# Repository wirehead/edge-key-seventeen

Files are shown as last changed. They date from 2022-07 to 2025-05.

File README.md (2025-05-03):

# edge-key-seventeen: A 17 key standard-layout numeric keypad plus encoders

I like numeric keypads.  They come in handy when I am working with CAD packages and stuff.  So you can see this as a piece of quiet rebellion against the world of hipster 40% or 60% fancy keyboards but one that still gives you a durable, fancy, interesting, artisanal, hand-crafted, mechanically-keyed product at the end of it.

## Prior art

This is partially developed using [Ruiqi Mao's Keyboard PCB guide](https://github.com/ruiqimao/keyboard-pcb-guide) as a reference... except that I'd suggest you don't actually use that guide as a reference because it's got some inaccuracies and at this point is old and unmaintained.  It turns out that, because I was designing it around parts that I already was comfortable with using and based it off of prior designs, I'd managed to sidestep all of the problems.  The current hotness is arguably the [ai03 Keyboard PCB](https://wiki.ai03.com/books/pcb-design) guide which seems to be newer and more accurate.

Otherwise, this has design lineage through a few earlier designs I cooked up but won't bother posting because they were mostly design experiments and aren't really useful for anyone.

## The design

### Design goals

* Be mostly standard in being designed for the QMK firmware, use Cherry MX keyswitches and standard-sized keycaps, etc.
* Contain the 17 keys of a numeric keypad, plus maybe some encoders for the funs.
* Look vaguely interesting as just a PCB.
* Use parts I already had in my parts bin for other projects.

### Concrete technical spec

* 17 keys in the standard layout so you can use pretty much any standard-layout numeric keypad caps.
* 2 rotary encoders with push-buttons.
* ATMega32u4 processor
* USB-C port
* Extra ESD protection diodes and a polyfuse for durability
* Programming port that you shouldn't actually need to ever use.
* 9 4-pin SK6812 "NeoPixel" RGB LEDs pointed downward for underglow
* 6 M2.5 mounting holes
* Not quite able to fit in the 10cm x 10cm box because of the size of the keys.
* Puns on the silkscreen

### USB protection

I did a bunch of digging and datasheet reading.

Given that I'm plugging this into the USB port on my computer, I tend to go for safety.  Thus, there's a ESD diode to protect the USB lines from spikes, there's a polyfuse on the power line so it won't use too much power, there's the required capacitors, and there's a decoupling network to keep the EMI from the cable sheath from crossing over to the ground plane.  This is more than most of the development boards.

I also added a polyfuse in case you short power to ground so it will reduce the chances that things go really bad.

### Routing scheme

Col: PF0, PD4, PD5, PD3, PD2
Row: PB6, PC7, PC6. PB5, PB4
Encoders: PF5/PF6, PF1/PF4
Col -> Row

Neopixel: PB7

Numlock LED: PF7

## BOM

|Reference	 |Quantity	 |Value	 |Footprint|
|---|---|---|---|
|C10 	| 1	| 4.7 nF	| 0805 |
|C1,C2 	| 2	| 22 pF	| 0805 |
|C3 	| 1	| 10 uF	| 0805 |
|C4 	| 1	| 1 uF	| 0805 |
|C5,C6,C7,C8 	| 4	| 0.1 uF	| 0805 | 
|D1,D2,D3,D4,D5,D6,D7,D9,D10,D11,D12,D13,D14,D15,D16,D17,D18,D27,D28 | 19	1N4148	| SOD123 / Axial |
|D19,D20,D21,D22,D23,D24,D25,D26,D29 	| 9	| SK6812	| 5050 PLCC4 |
|D30 | 1 | 5mm LED | |
|D8 	| 1	| PRTR5V0U2X_215	| TO-253-4 |
|F1 	| 1	| 500 mA Polyfuse	| 1206 |
|H1-H6 	| 6	| Mounting Hole	| M2.5 |
|J1 	| 1	| MicroUSB	| GCT USB4085-GF-A |
|J2 	| 1	| AVR-ISP-6	| 2x03 2.54mm pitch vertical SMD |
|MX1,MX2,MX3,MX4,MX5,MX6,MX7,MX9,MX10,MX11,MX12,MX13,MX14,MX17 | 14	| Cherry MX	|1U |
|MX8 MX15 	| 2	| Cherry MX	| 2U Vertical |
|MX16 	| 1	| Cherry MX	| 2U Horizontal |
|R1 	| 1	| 1M | 0603 |
|R2,R3 	| 2	| 22 | 0603 |
|R4,R5	| 2	| 10k | 0805 |
|R6,R8  | 2 | 5.1k | 0603 | 
|R7 | 1	| 1 M | 0603 |
|R9,R10 | 1	| 330 | 0805 |
|S1 | 1	| Toggle switch	| C&K KSR223GLFG | 
|SW1,SW2 | 2	| Rotary_Encoder_Switch	| PEC11R-4215F-S0024-0-0-0 |
|U1 | 1	| ATMEGA32U4 | TQFP-44 |
|Y1 | 1	| 16 MHz | HC49-U |

## Construction

The gerber files are as I upload to JLCPCB to be fabbed.

If other people start wanting to try and fab this board, I'll write an actual proper assembly guide. :)

Either way, the important points to consider are:

* Everything should be solderable with a regular old temperature-controlled ESD-protected soldering iron.
* You don't need to populate J2 unless you get yourself in deep trouble.
* The keyboard diodes are hybrid footprints that can use either a SOD-123 surface mount diode or an axial one.  I actually find SOD-123's easier to solder all told but I'm probably at least a bit odd.
* You can use either PCB-mount or plate-mount keyswitches and there are holes for PCB-mounted stabilizers.
* You can use a set of Mill-Max 7305-0-15-15-47-27-10-0 maybe the new 3305-1-15-15-47-27-10-0 receptacle connectors so that the keyswitches can be hot-swapped -- The 3305-X series is a new part specifically designed for keyswitches.

### Initial bootstrapping

You should just be able to program a freshly constructed board to the USB port and use the QMK programming tool to put an appropriate firmware on the board with the default bootloader.

I need to actually submit the upstream patches for QMK.

### Mounting holes

There are 6 M2.5 sized mounting holes in semi-convenient locations.

### Chassis design

This will appear later, still working on it!

## Changelog

### v1.0 rev 1

### v1.0 rev 2

* MicroUSB replaced with USB-C
* RS-187R05A2-DS button replaced with KSR223G LFG
* RG-49 Crystal a 3.2x2.5mm SMT 
* KiCAD 6.x instead of KiCAD 5.x

### Things I would change next time

* I might try to trim a few mm off of each of the edges.
* I might remove the hybrid SOD123/Axial feature because I actually solder SOD123's faster than I solder axial parts these days.
* The programming port is kinda annoying in the layout and I guess I need to look at more alternatives in the rare case you need to bootloader it.

## License



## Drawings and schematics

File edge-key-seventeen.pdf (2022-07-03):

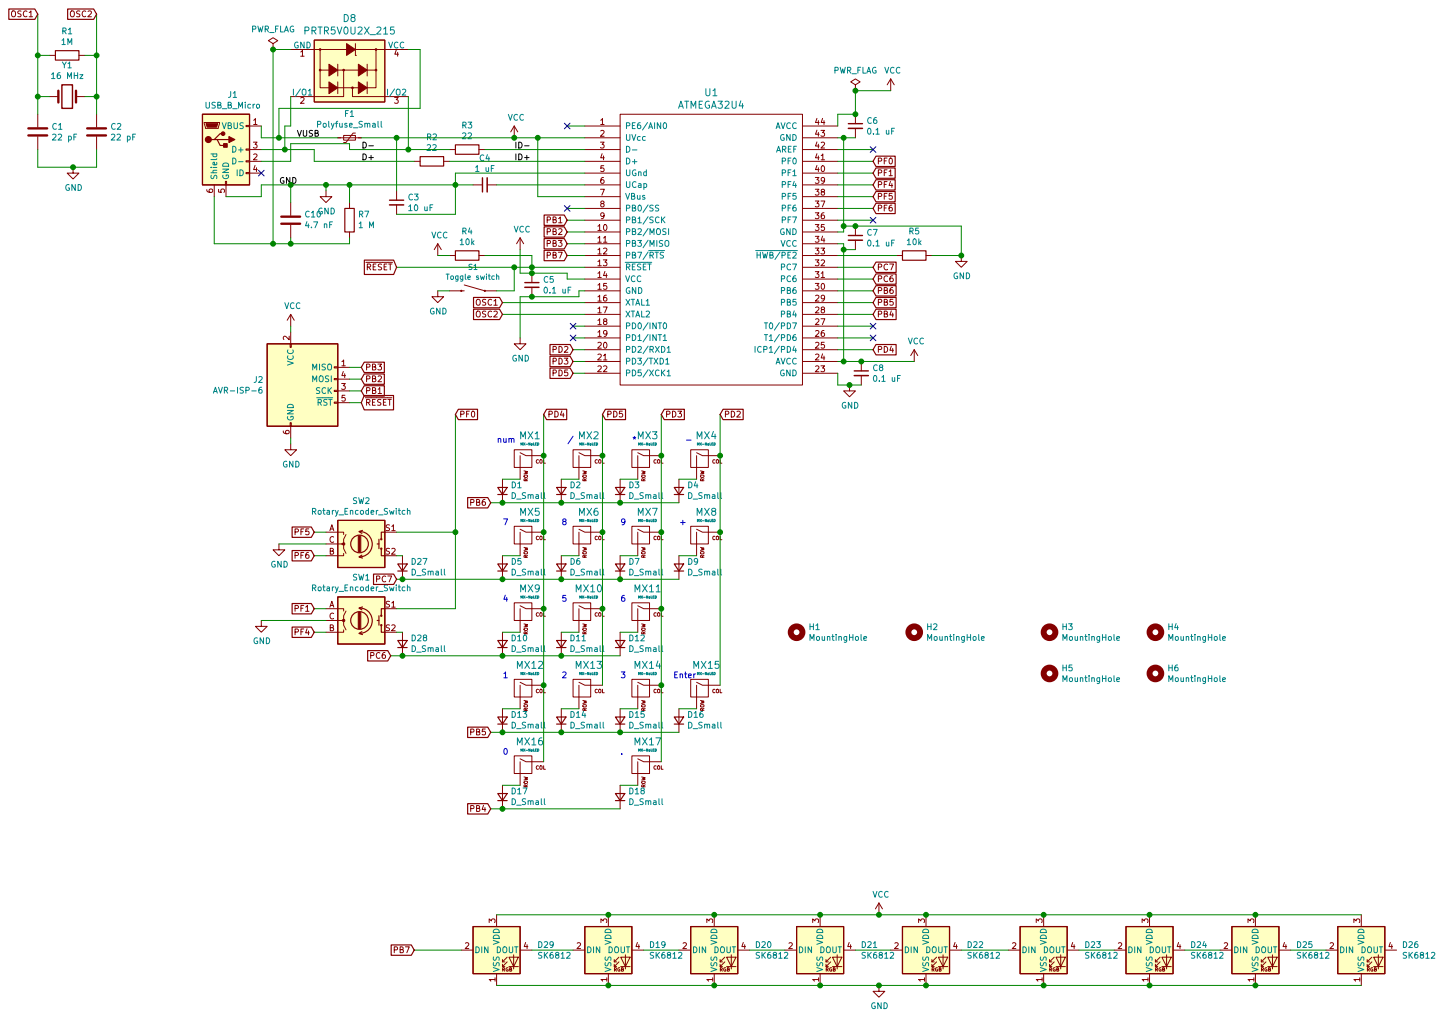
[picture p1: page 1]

2 SCK 3 MOSI 4 RST 5 GND

MX-NoLED COL ROW MX3

MX-NoLED COL ROW MX12

MX-NoLED COL ROW MX16

3 DOUT 4 D19 SK6812 VSS RGB 1 DIN 2 VDD

3 DOUT 4 D24 SK6812 VSS RGB 1 DIN 2 VDD

3 DOUT 4 D25 SK6812 VSS RGB 1 DIN 2 VDD

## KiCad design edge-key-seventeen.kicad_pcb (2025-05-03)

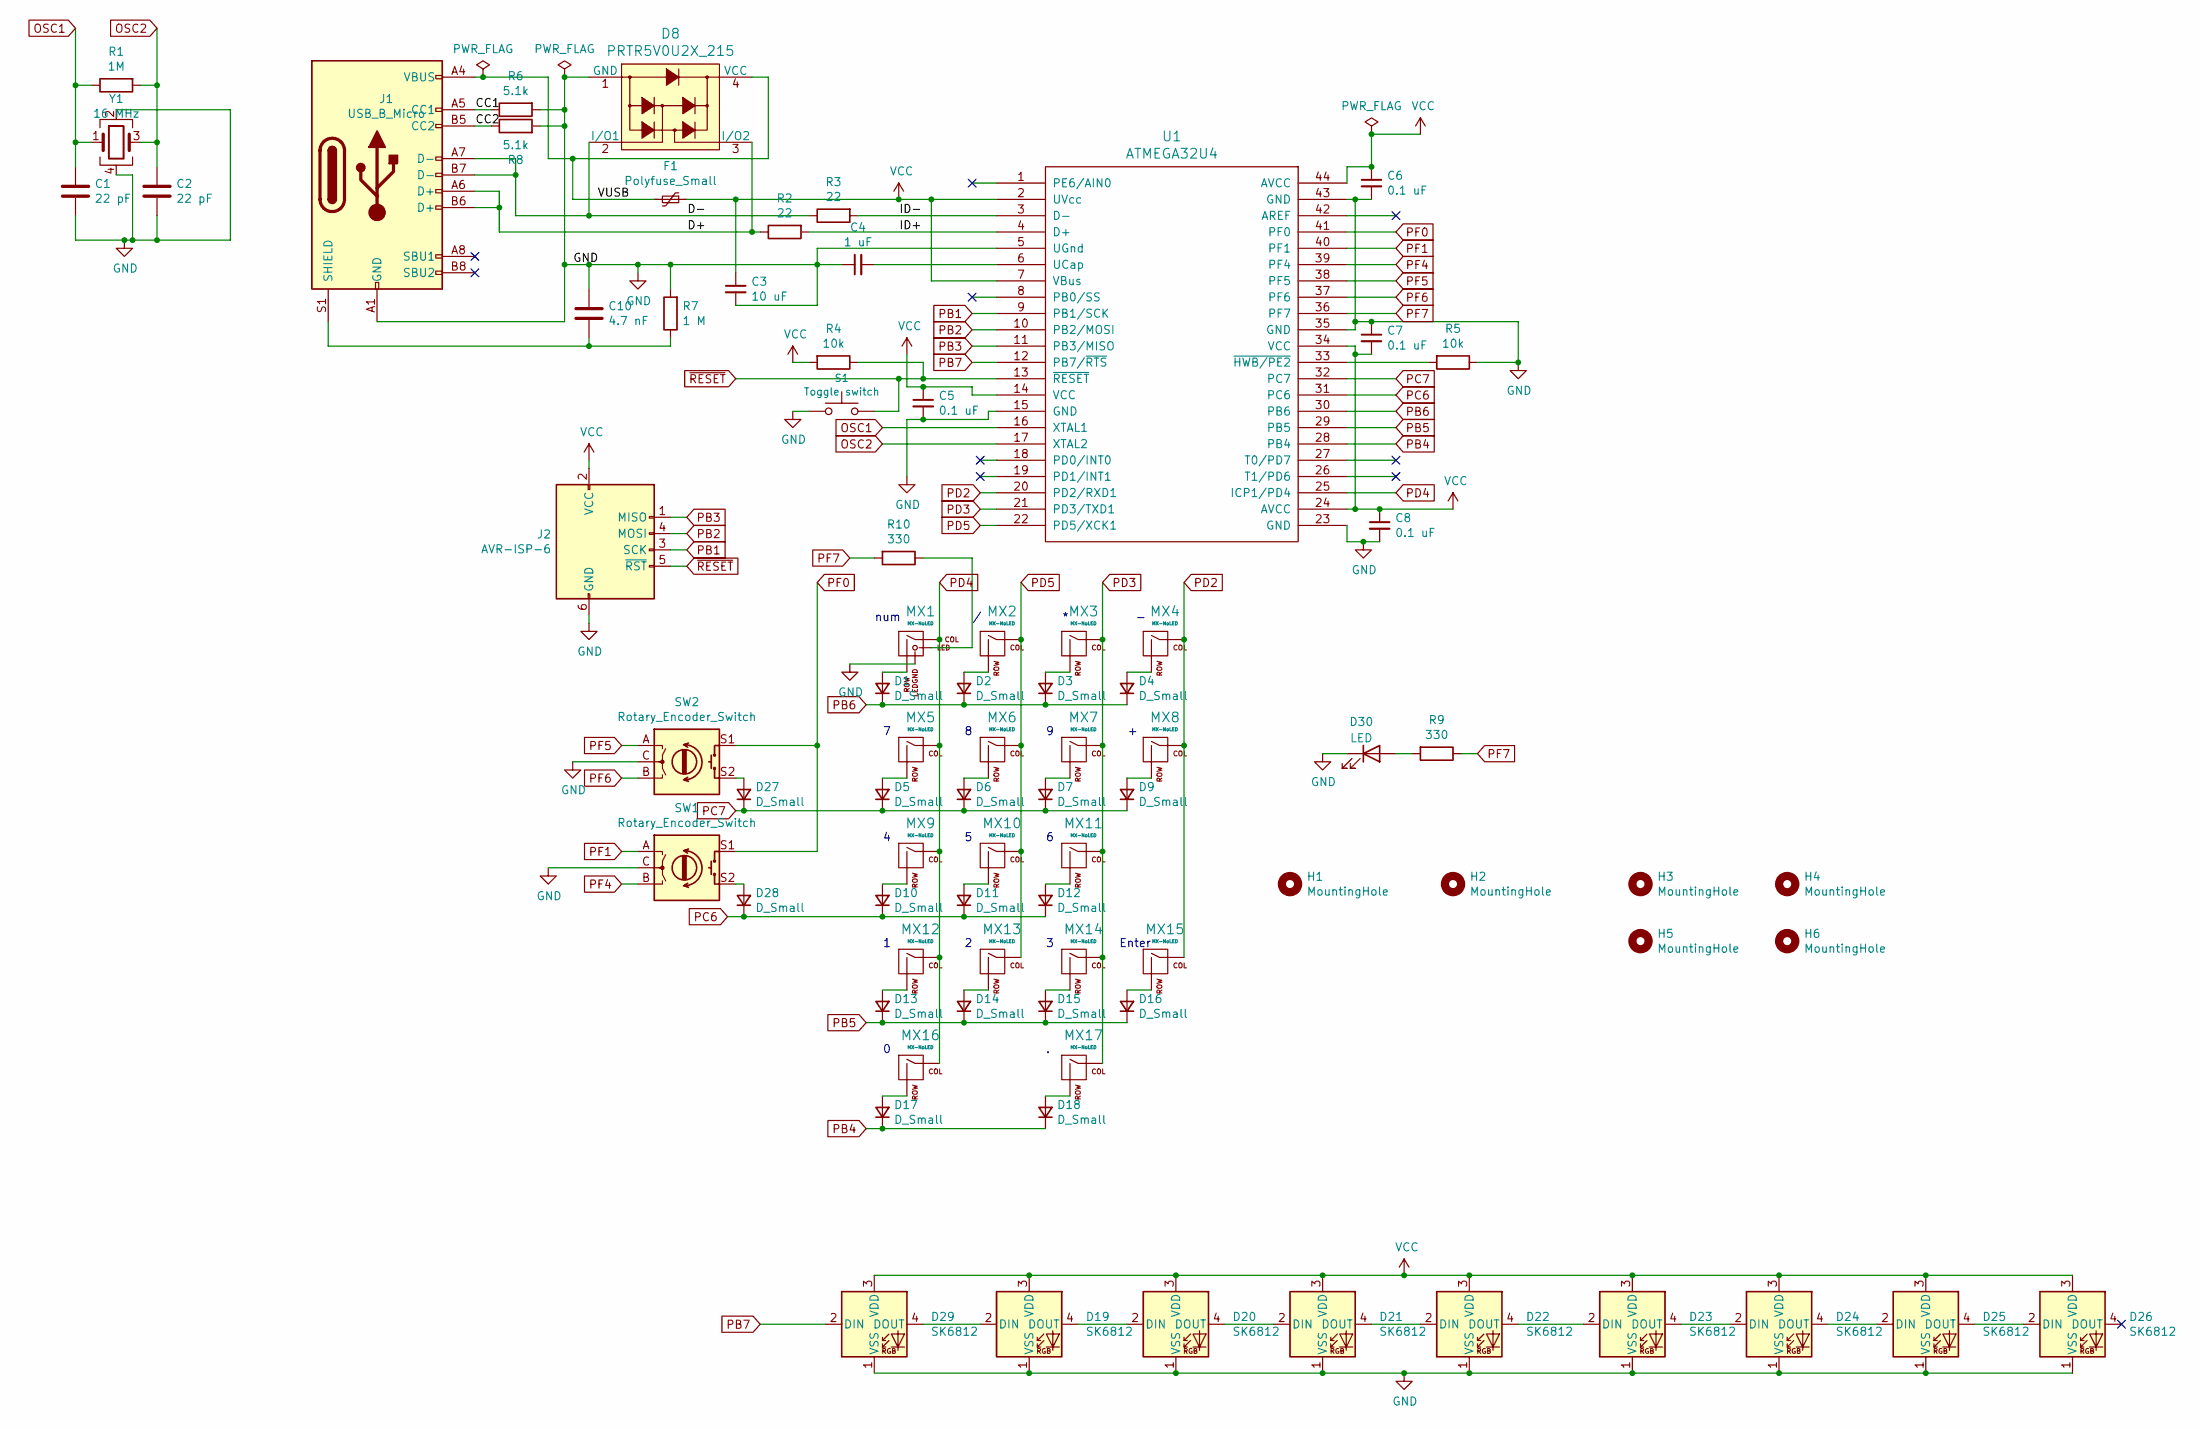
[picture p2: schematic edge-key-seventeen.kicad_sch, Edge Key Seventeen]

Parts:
C1, C2: 22 pF; C_0805_2012Metric_Pad1.15x1.40mm_HandSolder
C3: 10 uF; C_0805_2012Metric_Pad1.15x1.40mm_HandSolder
C4: 1 uF; C_0805_2012Metric_Pad1.15x1.40mm_HandSolder
C5, C6, C7, C8: 0.1 uF; C_0603_1608Metric_Pad1.08x0.95mm_HandSolder
C10: 4.7 nF; C_0603_1608Metric_Pad1.08x0.95mm_HandSolder
D1, D2, D3, D4, D5, D6, D7, D9, D10, D11, D12, D13, D14, D15, D16, D17, D18, D27, D28: D_Small; D_SOD123_axial
D8: PRTR5V0U2X_215; SOT-143_Handsoldering; MPN PRTR5V0U2X,215; Digi-Key_PN 1727-3884-1-ND
D19, D20, D21, D22, D23, D24, D25, D26, D29: SK6812; LED_SK6812_PLCC4_5.0x5.0mm_P3.2mm
D30: LED; LED_D5.0mm
F1: Polyfuse_Small; Fuse_1206_3216Metric_Pad1.42x1.75mm_HandSolder
H1, H2, H3, H4, H5, H6: MountingHole; MountingHole_2.7mm_M2.5
J1: USB_B_Micro; USB_C_Receptacle_GCT_USB4085
J2: AVR-ISP-6; PinHeader_2x03_P2.54mm_Vertical_SMD
MX1: MX-NoLED; MXOnly-1U
MX2, MX3, MX4, MX5, MX6, MX7, MX9, MX10, MX11, MX12, MX13, MX14, MX17: MX-NoLED; MXOnly-1U-NoLED
MX8, MX15: MX-NoLED; SW_Cherry_MX_2.00u_Vertical_PCB_nosilk
MX16: MX-NoLED; MXOnly-2U-NoLED
R1: 1M; R_0603_1608Metric_Pad0.98x0.95mm_HandSolder
R2, R3: 22; R_0603_1608Metric_Pad0.98x0.95mm_HandSolder
R4: 10k; R_0805_2012Metric_Pad1.15x1.40mm_HandSolder
R5: 10k; R_0805_2012Metric_Pad1.20x1.40mm_HandSolder
R6, R8: 5.1k; R_0603_1608Metric_Pad0.98x0.95mm_HandSolder
R7: 1 M; R_0603_1608Metric_Pad0.98x0.95mm_HandSolder
R9, R10: 330; R_0805_2012Metric_Pad1.20x1.40mm_HandSolder
S1: Toggle switch; SW_KSR223GLFG
SW1, SW2: Rotary_Encoder_Switch; Bourns-PEC11R-4215F-S0024-0-0-0
U1: ATMEGA32U4; TQFP-44_10x10mm_P0.8mm
Y1: 16 MHz; Crystal_SMD_3225-4Pin_3.2x2.5mm_HandSoldering

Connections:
/CC1: J1.A5 (CC1), R6.1
/CC2: J1.B5 (CC2), R8.1
/D+: D8.3 (I/O2), J1.A6 (D+), J1.B6 (D+), R2.1
/D-: D8.2 (I/O1), J1.A7 (D-), J1.B7 (D-), R3.1
/ID+: R2.2, U1.4 (D+)
/ID-: R3.2, U1.3 (D-)
/VUSB: D8.4 (VCC), F1.2, J1.A4 (VBUS), J1.A9 (VBUS), J1.B4 (VBUS), J1.B9 (VBUS)
GND: C1.2, C2.2, C3.2, C4.1, C5.2, C6.2, C7.1, C8.2, C10.2, D8.1 (GND), D19.1 (VSS), D20.1 (VSS), D21.1 (VSS), D22.1 (VSS), D23.1 (VSS), D24.1 (VSS), D25.1 (VSS), D26.1 (VSS), D29.1 (VSS), D30.1 (K), J1.A1 (GND), J1.A12 (GND), J1.B1 (GND), J1.B12 (GND), J2.6 (GND), MX1.4 (LEDGND), R5.1, R6.2, R7.2, R8.2, S1.2, SW1.C, SW2.C, U1.5 (UGnd), U1.15 (GND), U1.23 (GND), U1.35 (GND), U1.43 (GND), Y1.2, Y1.4
unnamed: C4.2, U1.6 (UCap)
unnamed: C10.1, J1.S1 (SHIELD), R7.1
unnamed: D1.2 (A), MX1.2 (ROW)
unnamed: D2.2 (A), MX2.2 (ROW)
unnamed: D3.2 (A), MX3.2 (ROW)
unnamed: D4.2 (A), MX4.2 (ROW)
unnamed: D5.2 (A), MX5.2 (ROW)
unnamed: D6.2 (A), MX6.2 (ROW)
unnamed: D7.2 (A), MX7.2 (ROW)
unnamed: D9.2 (A), MX8.2 (ROW)
unnamed: D10.2 (A), MX9.2 (ROW)
unnamed: D11.2 (A), MX10.2 (ROW)
unnamed: D12.2 (A), MX11.2 (ROW)
unnamed: D13.2 (A), MX12.2 (ROW)
unnamed: D14.2 (A), MX13.2 (ROW)
unnamed: D15.2 (A), MX14.2 (ROW)
unnamed: D16.2 (A), MX15.2 (ROW)
unnamed: D17.2 (A), MX16.2 (ROW)
unnamed: D18.2 (A), MX17.2 (ROW)
unnamed: D19.2 (DIN), D29.4 (DOUT)
unnamed: D19.4 (DOUT), D20.2 (DIN)
unnamed: D20.4 (DOUT), D21.2 (DIN)
unnamed: D21.4 (DOUT), D22.2 (DIN)
unnamed: D22.4 (DOUT), D23.2 (DIN)
unnamed: D23.4 (DOUT), D24.2 (DIN)
unnamed: D24.4 (DOUT), D25.2 (DIN)
unnamed: D25.4 (DOUT), D26.2 (DIN)
unnamed: D27.2 (A), SW2.S2
unnamed: D28.2 (A), SW1.S2
unnamed: D30.2 (A), R9.2
unnamed: MX1.3 (LED), R10.1
unnamed: R5.2, U1.33 (~HWB/PE2)
OSC1: C1.1, R1.1, U1.16 (XTAL1), Y1.1
OSC2: C2.1, R1.2, U1.17 (XTAL2), Y1.3
PB1: J2.3 (SCK), U1.9 (PB1/SCK)
PB2: J2.4 (MOSI), U1.10 (PB2/MOSI)
PB3: J2.1 (MISO), U1.11 (PB3/MISO)
PB4: D17.1 (K), D18.1 (K), U1.28 (PB4)
PB5: D13.1 (K), D14.1 (K), D15.1 (K), D16.1 (K), U1.29 (PB5)
PB6: D1.1 (K), D2.1 (K), D3.1 (K), D4.1 (K), U1.30 (PB6)
PB7: D29.2 (DIN), U1.12 (PB7/~RTS)
PC6: D10.1 (K), D11.1 (K), D12.1 (K), D28.1 (K), U1.31 (PC6)
PC7: D5.1 (K), D6.1 (K), D7.1 (K), D9.1 (K), D27.1 (K), U1.32 (PC7)
PD2: MX4.1 (COL), MX8.1 (COL), MX15.1 (COL), U1.20 (PD2/RXD1)
PD3: MX3.1 (COL), MX7.1 (COL), MX11.1 (COL), MX14.1 (COL), MX17.1 (COL), U1.21 (PD3/TXD1)
PD4: MX1.1 (COL), MX5.1 (COL), MX9.1 (COL), MX12.1 (COL), MX16.1 (COL), U1.25 (ICP1/PD4)
PD5: MX2.1 (COL), MX6.1 (COL), MX10.1 (COL), MX13.1 (COL), U1.22 (PD5/XCK1)
PF0: SW1.S1, SW2.S1, U1.41 (PF0)
PF1: SW1.A, U1.40 (PF1)
PF4: SW1.B, U1.39 (PF4)
PF5: SW2.A, U1.38 (PF5)
PF6: SW2.B, U1.37 (PF6)
PF7: R9.1, R10.2, U1.36 (PF7)
VCC: C3.1, C5.1, C6.1, C7.2, C8.1, D19.3 (VDD), D20.3 (VDD), D21.3 (VDD), D22.3 (VDD), D23.3 (VDD), D24.3 (VDD), D25.3 (VDD), D26.3 (VDD), D29.3 (VDD), F1.1, J2.2 (VCC), R4.2, U1.2 (UVcc), U1.7 (VBus), U1.14 (VCC), U1.24 (AVCC), U1.34 (VCC), U1.44 (AVCC)
~RESET: J2.5 (~RST), R4.1, S1.1, U1.13 (~RESET)

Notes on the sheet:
Enter
num

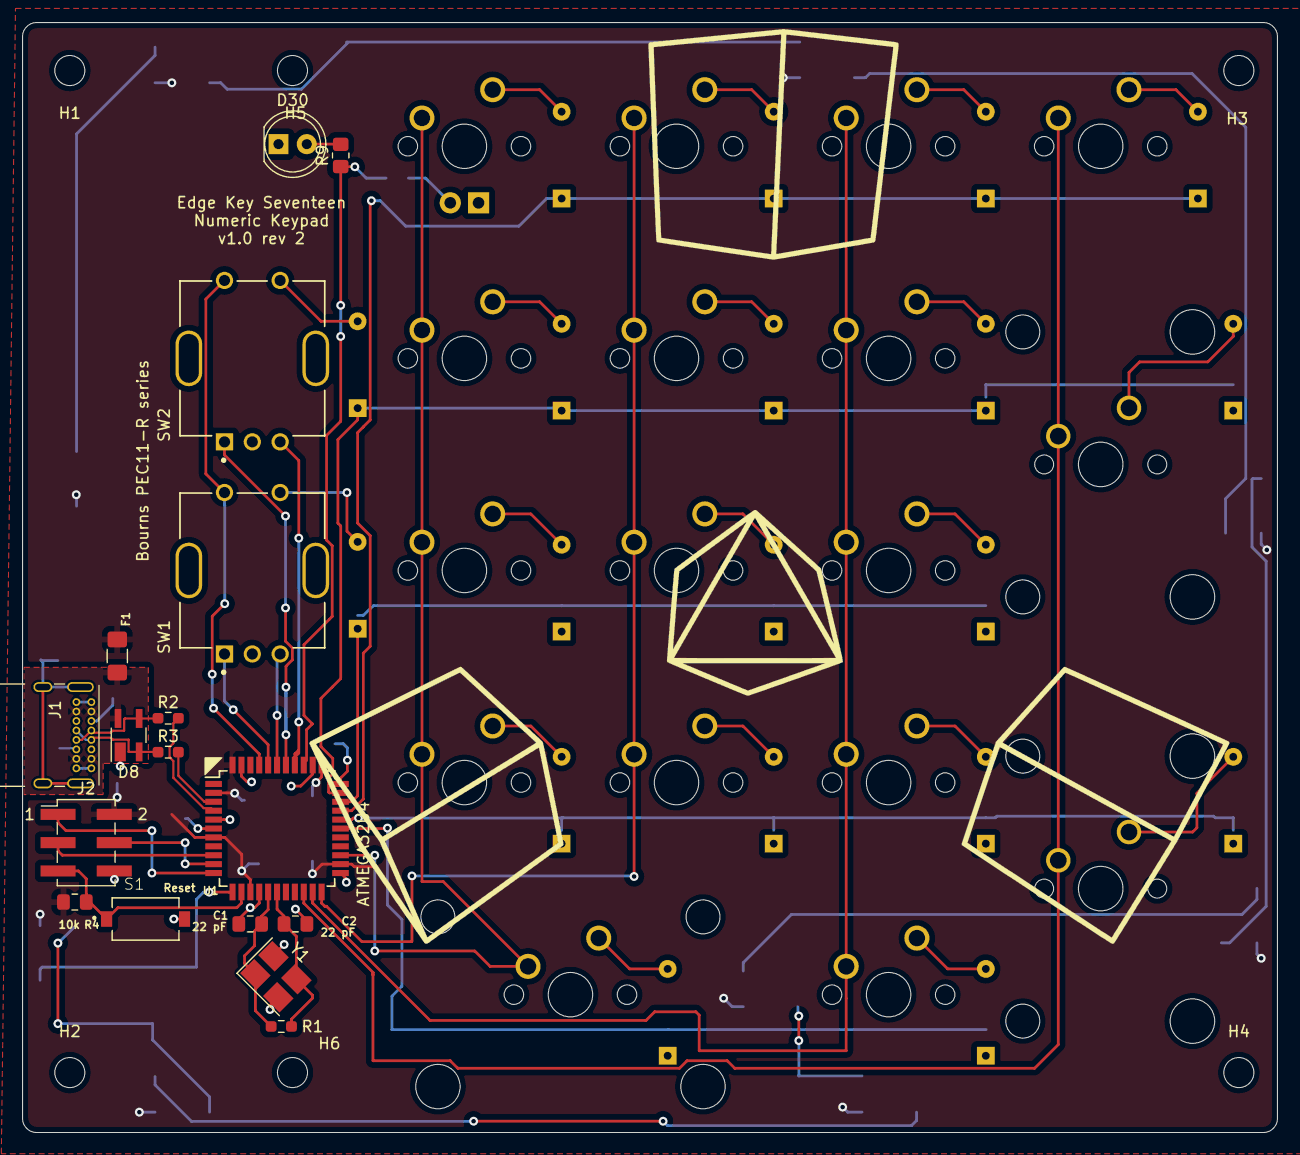
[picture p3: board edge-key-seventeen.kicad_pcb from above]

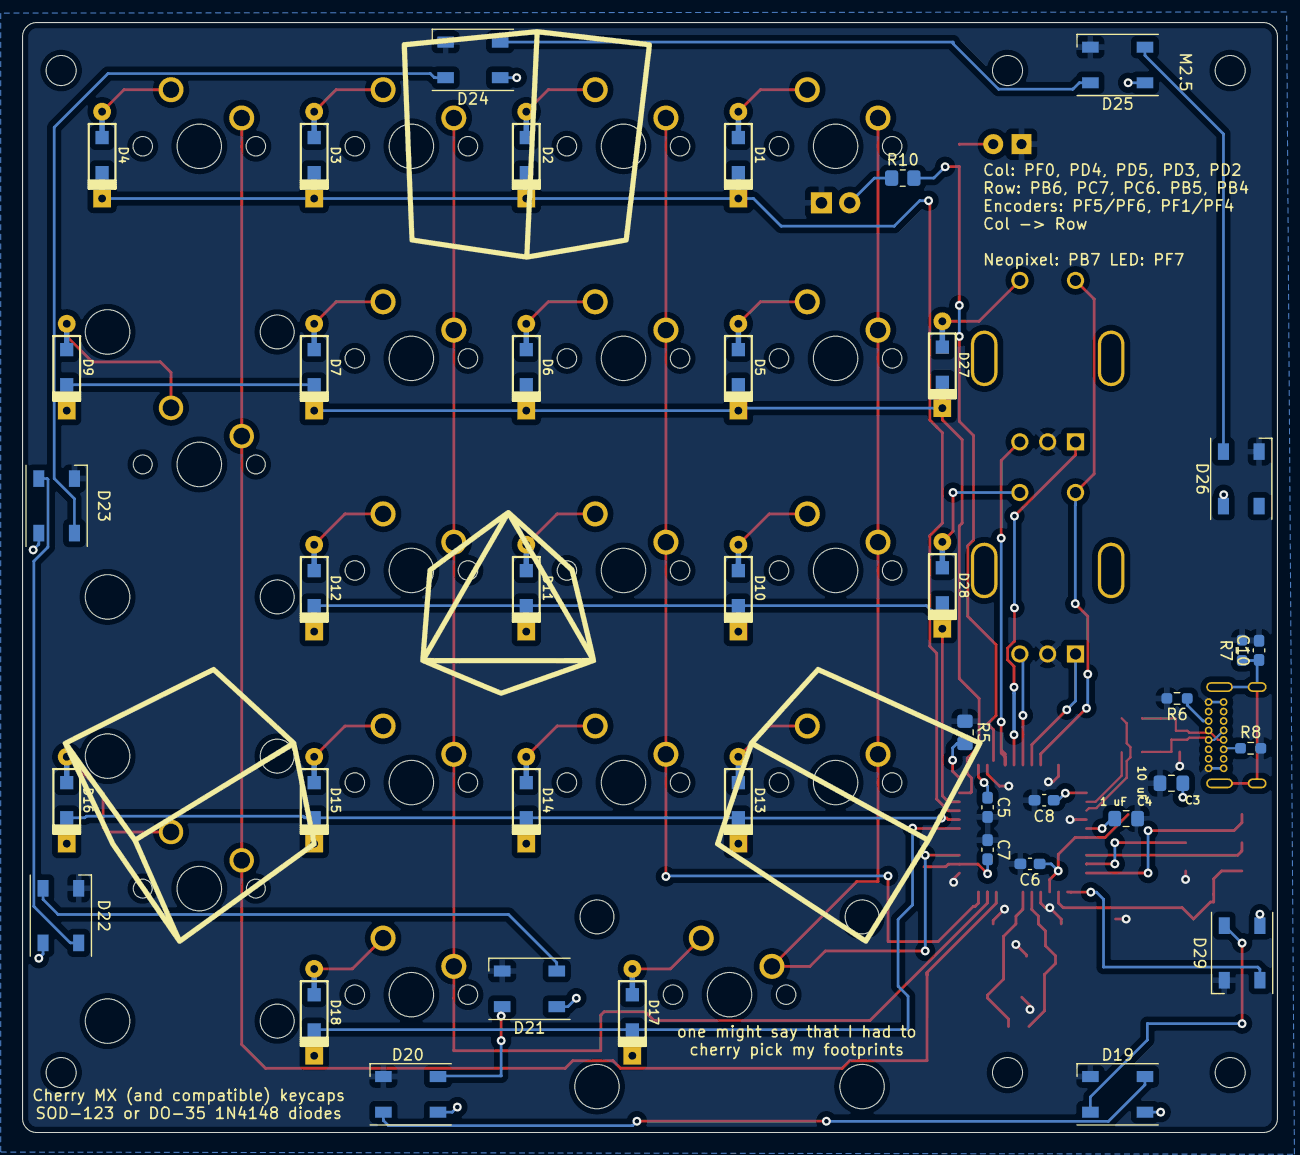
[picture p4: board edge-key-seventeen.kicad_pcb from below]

Board: 2 copper layers, 112.7 x 99.7 mm, 82 parts (41 on the bottom side), 63 nets.

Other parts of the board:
Ref**: Val**; keyboard-bit
Ref**#2: Val**; keyboard-bit

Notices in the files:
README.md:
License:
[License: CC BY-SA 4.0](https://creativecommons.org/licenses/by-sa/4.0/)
